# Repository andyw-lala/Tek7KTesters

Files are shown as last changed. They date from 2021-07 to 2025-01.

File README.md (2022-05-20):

# Tek7KTesters

Project to create modern test fixtures/plug-ins for the Tektronix 7000-series scope mainframes.
For more info on the 7000 series, see the excellent [Tekwiki](https://w140.com/tekwiki/wiki/Introduction_to_the_7000-Series).

7000-series calibration plug-ins are a rare beast, and usually expensive when they can be found.

This project hopes to create some new calibration & test solutions, with circuit ideas and software that can be reused, mixed-and-matched, extended, and improved. Where appropriate, modern chip-level solutions are encouraged to be used, examples include: differential drivers (both analog and LVDS), and microcontrollers.

Some of this work may be applicable or portable to other Tek plug-in based scopes, such as the 5000 series, but I don't own any of those (yet.)

## Contents:

### [Tek 7K Breakout Board](/Breakout)
This is a simple breakout board to facilitate experimentation and development using the Tek 7000 backplane connections.

### [Pattern Generator](/Pattern)
Circuit to generate test patterns, consisting of vertical lines, horizontal lines, vertical and horizontal lines, and dots.
Based on the Infineon (nee Cypress) PSOC5LP, plus required external circuitry.

### [Readout Interface](/Readout)
Circuit to interface the mainframe's readout subsystem to the PSoC, to permit displaying of arbitrary information, and/or testing of the mainframe readout system.

## Licence
All work here is covered by the MIT Licence, which is simple and permissive.

## Background
There is information to be found in many places, but a great starting point is [Tektronix 7000-Series Plug-in to Mainframe Interface Manual](https://w140.com/tekwiki/images/7/7c/Tek_7000-series_plug-in_mainframe_interface_manual_ocr.pdf). Originally a Tek-internal engineering document, now freely available.

Manuals for original calibration/test fixtures:
* [067-0587-01](http://w140.com/tek_067_0587_01.pdf)
* [067-0587-02](http://w140.com/tek-067-0587-02.pdf)
* [067-0587-10](http://w140.com/tek_067-0587-10_service.pdf)
* [067-0711-99](https://w140.com/tekwiki/images/8/87/Tek_067-0711-99.pdf)
* [7M13](https://w140.com/tekwiki/images/3/33/070-1577-00.pdf)

The [TekScopes mailing list](https://groups.io/g/TekScopes) is an invaluable source of knowledge, experience, and expertize on all Tek oscilliscopes, not just the 7000-series.

## TODO
* Fast edge driver, ideas include LVDS drivers, or MAX3949 (like the Leo Bodnar pulser I have that happily does <40pS edges, I like this because it is configurable to some extent)
* Levelling amp, will likely think about this last, as I believe it will be the most difficult subsystem to get right, and make repeatable, especially up to 7104 bandwidths..

## Disclaimer
This project is presented as-is, all work and consequences are your sole responsibility. Do not work on Tek 7000 scopes unless you have the skills and knowledge to work safely, they contain **lethal** voltages. You perform all work at your own risk, and I have no responsibility for any damage or injury whatsoever.

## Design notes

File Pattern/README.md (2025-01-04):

# Pattern Generator
Generate various test patterns, including:
* Horizontal lines
* Vertical lines
* Cross-hatch (combination of horizontal and vertical lines)
* Field of dots

The lines can either be coarse and match only the major graticule markings (11 horizontal, 9 vertical), or fine and align with both major and minor graticule markings (51 total horizontal, 41 total vertical.)

The field of dots is designed to produce a dot at every intersection of the major graticule markings only.
Optionally produce Z axis signal(s) to highlight the central graticule lines (and also all major graticule markings when producing the fine liones or crosshatch.

All signals are brought out to front panel connectors (100mV per division, single-ended), and driven to the approriate backplane connections (50mV per division differential.)

## Overview
There are 4 signal sources used in various combinations to support each mode:
1. Ramp Generator

   This uses a current DAC in the PSoC to charge a capacitor, generating a linear ramp. This signal is then conditioned to be symmetrical around ground, and have the approriate amplitude.
2. X & Y Step Generators

   These are identical, and each also use a current DAC in the PSoC to develop a voltage across a precision resistor. These signals are then conditioned in a similar manner to the ramp signal.
3. Z Axis driver

   This uses a voltage DAC in the PSoC, to provide a voltage that is converted into a control current in the range -4 to +4 mA which can modulate the trace intensity (max intensity to full blanking, respectively.)

The ramp and step signals are highly configurable, and also switched/routed according to the desired pattern and the location of the test plug-in in the mainframe (more on this later.)
In addition to directly driving the approriate backplane signals, these are also brought out to front panel BNC connectors. Usually one of these is used to connect to a suitable plug-in to provide the "other" signal (e.g., in a vertical slot, if the tester is using a horizontal slot.)

The Tek 067-0587-* fixtures could generate either 11 or 110 lines, with sweeps from 10Hz to 1MHz.
The new fixture can generate 11 or 51 vertical lines, and 9 or 41 horizontal lines, with sweeps from approximately 50Hz to 450KHz, and independently control the ramp repetition frequency in 500nS steps. At very slow speeds, the signals are so sparse that it can be difficult to visually align with the graticule markings; at the very fastest speeds, the software can begin to have trouble setting up additional signals such as the Z Axis output, resulting in inconsistent trace intensity.
The independent and highly configurable ramp time and ramp repetition frequency , combined with flexible signal routing allows for a great range of possible test patterns and speeds.

# Additional Signals
In addition to the differential signals and Aux Z axis outputs provided to the backplane, and the vertical and horizontal front panel outputs, several additional signals are implemented.
## Outputs
The following signals are provided:
* Sweep Trigger Output (front panel BNC) 
* \+ Trigger Out (backplane A13)
* Sweep Gate (backplane A1)
* Hold Off (backplane B4)
* Aux Y (backplane B16)
## Inputs
The following inputs are used:
* Chop Drive (backplane A5)

The following inputs are terminated in 50Ohm, but not used:
* +/- Trigger In (backplane A20/B20)

[CY8CKIT-059](https://www.mouser.com/ProductDetail/Cypress-Semiconductor/CY8CKIT-059)

[PSoC Creator IDE](https://www.cypress.com/products/psoc-creator-integrated-design-environment-ide)

TODO:
* block diagram
* PSoC Creator files

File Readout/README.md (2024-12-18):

# Readout-related circuits
The 7000-series readout circuitry is a clever, subtle, and novel solution, as you would expect once you learn that the designer was [Barrie Gilbert](https://w140.com/tekwiki/wiki/Barrie_Gilbert).
It is based on circuitry in the mainframe scanning the modules for characters to display in specific timeslots.
There are 10 possible timeslots (character positions) per screen location, and 2 screen locations per plug-in bay (e.g., 8 total screen locations in a 7904A, for a maximum total of 80 characters, though far fewer are displayed in normal operation.)
Display characters, or other metadata, are encoded in each timeslot by two currents (row and column) per location.
Currents are encoded in 100uA steps.
Modules need to always be prepared to sink either two or four currents to drive the display, but while the timeslot signals are simply bussed across all plug-in bays, the mainframe is paying attention to only one plug-in at a time (there is no indication to a plug-in that it is the active one.)
The system can be fully implemented by passive components and wiring and/or switches, including modifying scales/prefixes. Changes can be accomplished simply by summing currents, and common scope operations (e.g., input sensitivity modification by x10, x100, x1000 probes) are easily implemented by plug-ins using simple, but sometimes subtle, solutions.

## Interfaces
There are two interfaces needed to interact with the 7000-series readout system - one from the mainframe to the plug-ins and one from the plug-ins to the mainframe:

### Timeslot Signals

There are ten timeslot scanning signals from the mainframe to the plug-in.
Each individual timeslot signal is activated in a repeating sequence.
Each pulse is ~130-250uS wide and drives from ground to -15V, but is carefully slew-rate controlled, in order to avoid generating noise in sensitive plug-ins.
The timing is not explicitly specified in the documentation (that I can find), specifically when the current sinks are sampled, or setup/hold times.

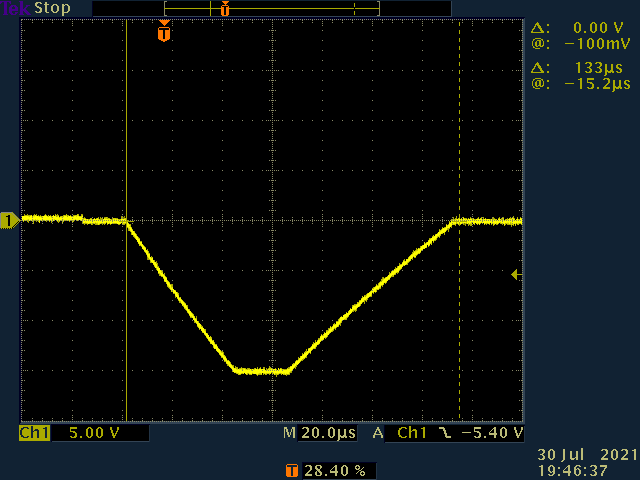
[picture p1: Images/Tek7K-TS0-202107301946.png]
TS0 Pulse


The above image clearly shows a timeslot pulse that is around 130us wide, with a plateau at -15V between approximately 45us and 65us, which is where the sampling must occur for the specified resistor values to generate the appropriate currents.

More details can be found on [TekWiki](https://w140.com/tekwiki/wiki/7000_series_readout_system).

# Interfacing to PSoC

Adapting the timeslot input circuitry used on the 7D11, the timeslot pulses from the mainframe are fed to a JFET, which is normally conducting, with its drain at 0V. When the TS pulse starts to go negative, the JFET will turn off, allowing the voltage at the drain to rise. Since the PSoC lacks schmitt trigger inputs, we use on-chip comparators with hysterisis enabled to condition the input signal. This circuit is implemented twice, once for TS1 and once for all the other TS signals, diode or-ed together. A 100K pull-down resistor on the JFET gate ensures a timely turn on of the fet as the diodes would otherwise isolate the gate. Although the TS1 signal strictly speaking does not require the diode, it is implemented so that the circuitry and timing seen by each timeslot is identical.

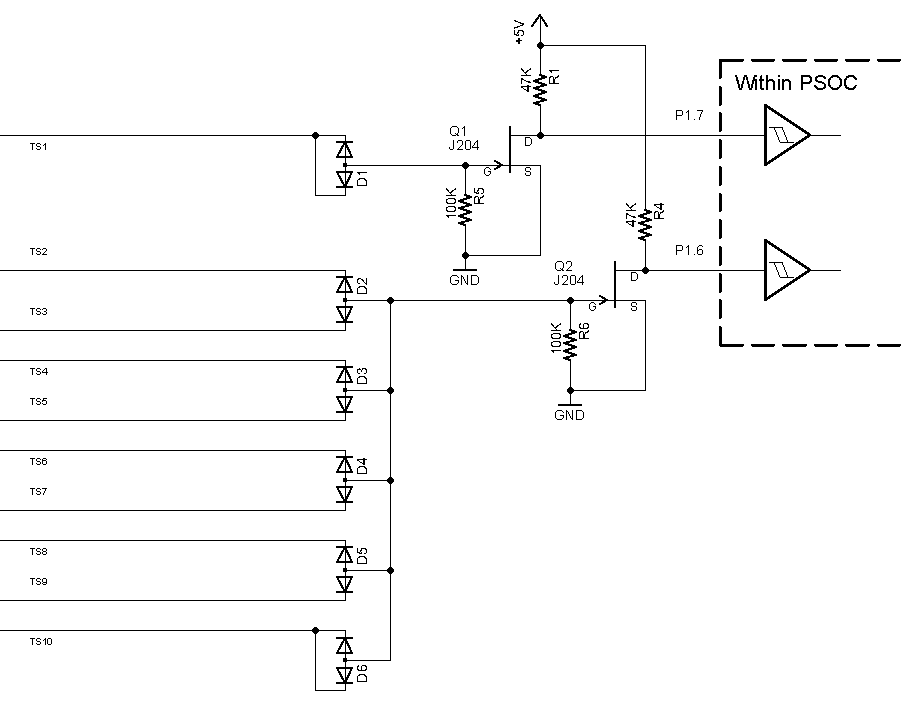
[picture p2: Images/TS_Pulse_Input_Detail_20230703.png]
Input Conditioning


This circuit offers approximately 57 uS lead-time from the input signal crossing the 1.024 V threshold to the bottom of the input pulse when the current sinks need to be set-up.

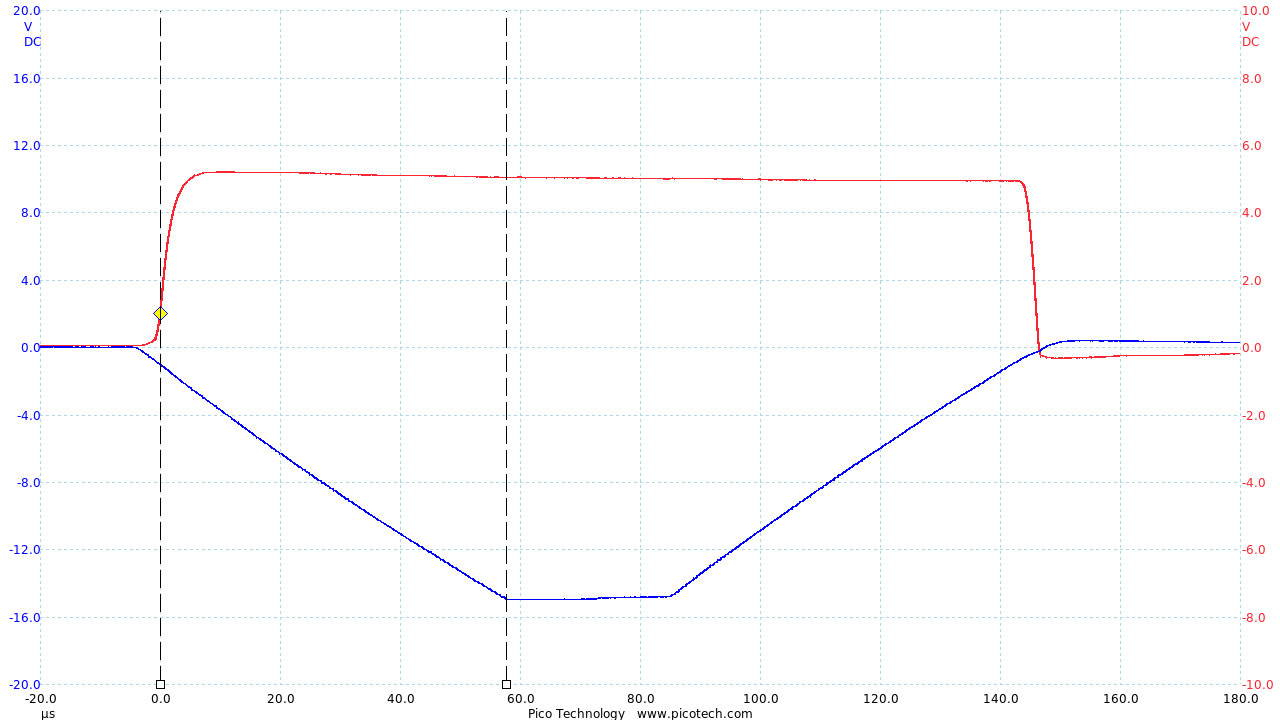
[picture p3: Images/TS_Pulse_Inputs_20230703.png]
Input Timing


The blue trace (LH axis) is the input pulse from the mainframe, red trace (RH axis) is the signal as seen by the PSoC.

The following image shows the same input pulse in blue, but the red trace reflects the time spent in the interrupt handler on the ARM CPU in the PSoC (note the timebase change from 20us to 10us per division.) The ISR is reading the timeslot value from the counter and then writing new values to the readout current circuitry via the shift registers described below. In practice, additional lookups will be involved, but that will hardly impact the duration of the ISR.

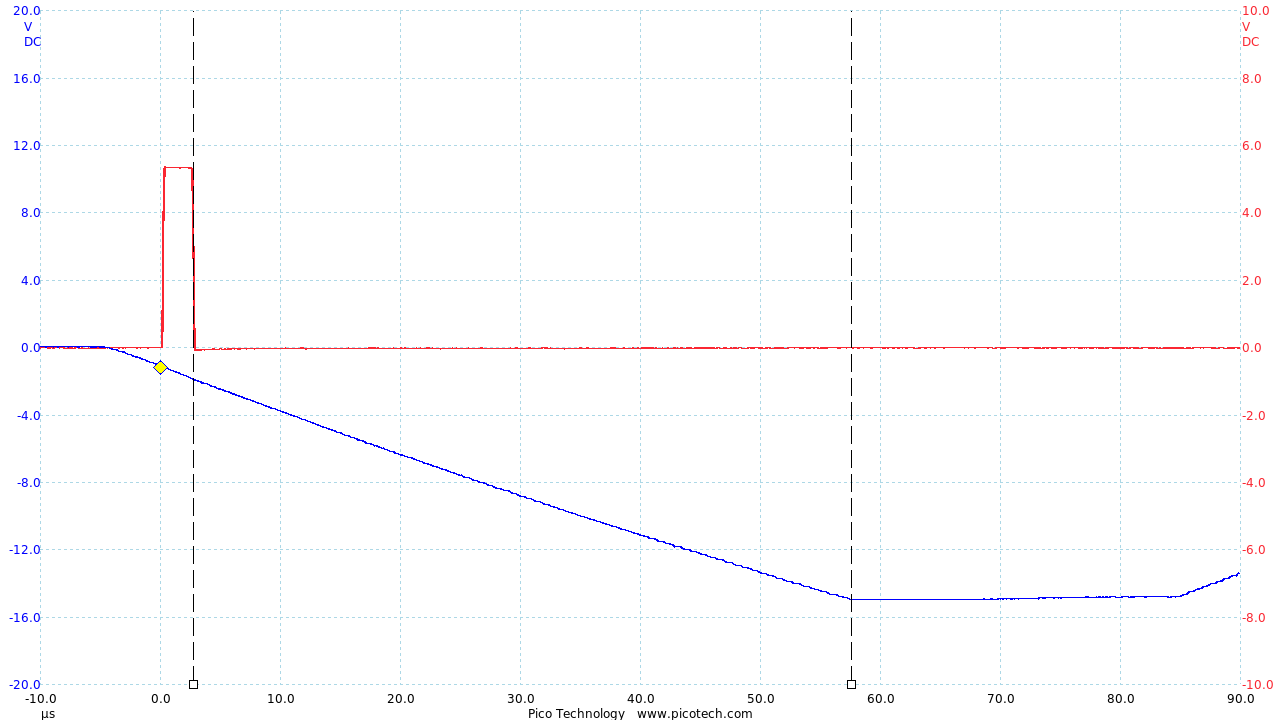
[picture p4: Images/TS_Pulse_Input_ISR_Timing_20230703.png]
Input ISR Timing


This demonstrates that the solution will work, and as long as we do not mask interrupts for extended periods we can use software to service the readout circuitry.

Note that should the PSoC become unable to service interrupts (due to firmware crash, reset, flashing, or debugger activity) the readout will not longer be updated for each timeslot, resulting in each display field filling with the same character (usually the last one written just before interrupts were no longer serviced.) Each display field can show different characters.

## PSoC Connectivity

### Inputs

The timeslot input circuitry uses two pins of analog I/O into the PSoC.
Internally these are conditioned via comparators (as described above) and used to maintain a counter of the most recent timeslot requested, and generate interrupts so that the firmware can determine the approriate row/column currents for each channel.

Combining the nine timeslot signals as shown reduces the number of input pins required, at the cost of obscuring specific timeslot outputs from the mainframe that may be malfunctioning.

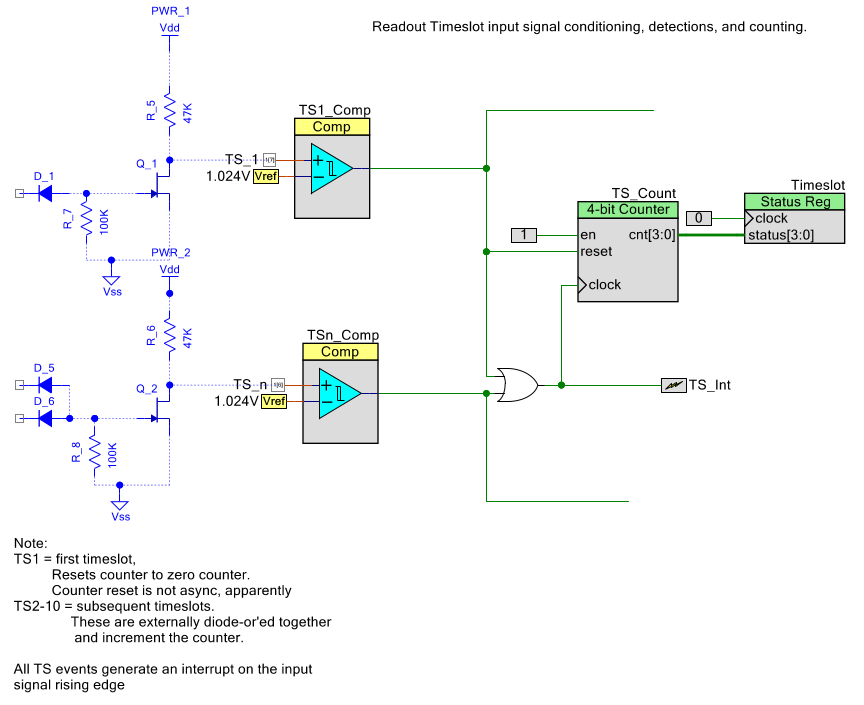
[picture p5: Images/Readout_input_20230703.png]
TS Input


### Outputs

Output requires 16 bits of digital GPIO for the maximum of four current sinks, while this may be possible directly with specific members of the PSoC device family, it was highly desirable to be able to use the CY8CKIT-059, meaning that the available GPIO pin count was constrained. Initially a Microchip MCP23S17 I/O expander using SPI was prototyped, but the final design uses two 74HC595 shift registers coupled with a simple driver circuit implemented in the PSoC as a write-only 16-bit port expander. Each 595 shift register implemets 8 bits (4 row + 4 column) required for one channel. These are daisy-chained, so that the PSoC clocks 16 bits out in one operation and then strobes the register clock line to simultaneously present all 16 bits to the current generation circuits.

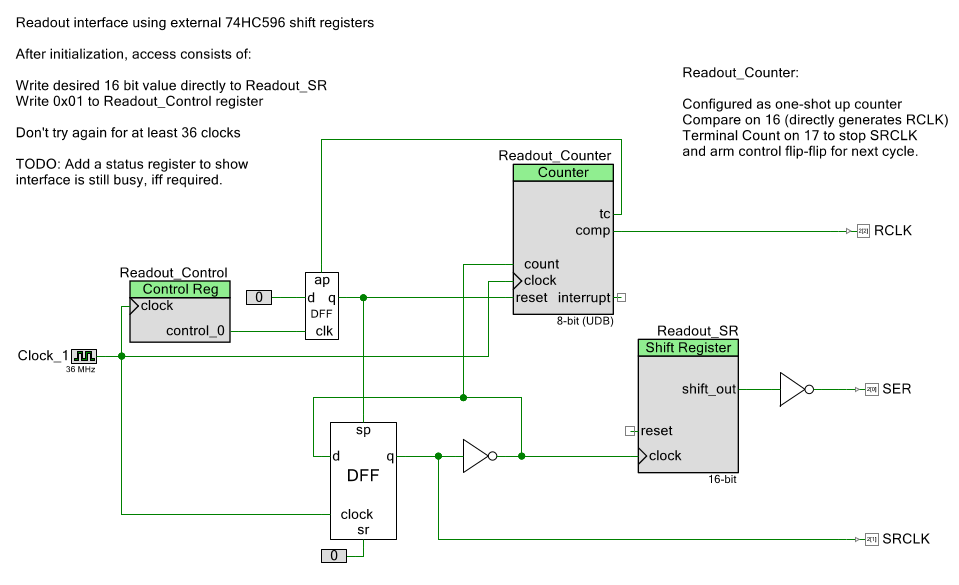
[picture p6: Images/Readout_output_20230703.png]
TS Output Logic


### Readout Row and Column Currents
Four identical current sinks (two channels, each with independent row & column currents) encode the data for the currently indicated timeslot.  
Channel 1 data will appear at the top of the screen, Channel 2 data will appear at the bottom of the screen.

The circuit used is shown below:

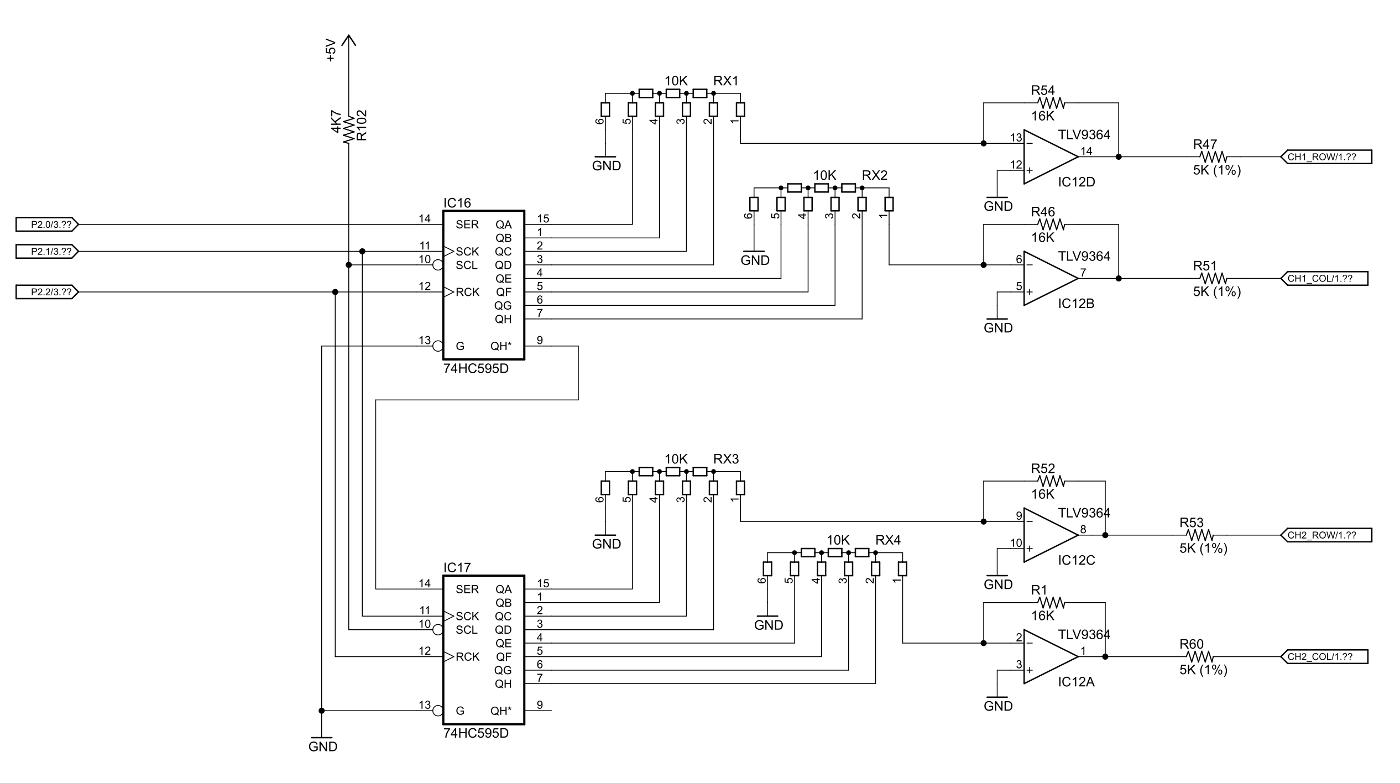
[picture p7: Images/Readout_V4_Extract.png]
Readout Current Sink


The parallel outputs of the shift registers drive four independent 4-bit [R-2R voltage DACs](https://en.wikipedia.org/wiki/Resistor_ladder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). These output 0 - 4.6875V, in 312.5mV steps, for values between 0 and 15 respectively. Note that R-2R ladders maintain a fixed impedance, equal to R regardless of input value.

As described above, the mainframe samples the current flowing out of the mainframe row and current sense pins on the backplane in 100uA steps when the timeslot signals are stable at -15V (the middle of the pulse.)
These mainframe row and current sense pins are nominally at ground.
The current is developed by applying negative voltages across fixed resistors connected to the mainframe row and column pins. Since 5K precision (1%) resistors are aleady used elsewhere in the design, this value was selected.
100uA corresponds to 500mV across a 5K resistor, therefore a simple inverting amplifier with a gain of -1.6 (recall that the impedance seen looking into the R-2R ladder will always be 10K, hence the feedback resistor of 16K) is used to convert the positive-going DAC output voltage into a suitable negative voltage. Converting each 312.5mV step from the DAC into -500mV at the output of the opamp, resulting in 100uA current per-step flowing out of the mainframe sense pins. The maximum negative voltage generated for a code of 15 is -7.5V.

Thus we can generate four independent 0 - 1500uA current sinks at 100uA resolution, using only 3 digital pins on the PSoC, and three low-cost ICs. The total PSoC pin count used for the readout interface is five: 2 analog inputs and three digital outputs.

## Demonstration of circuit in action
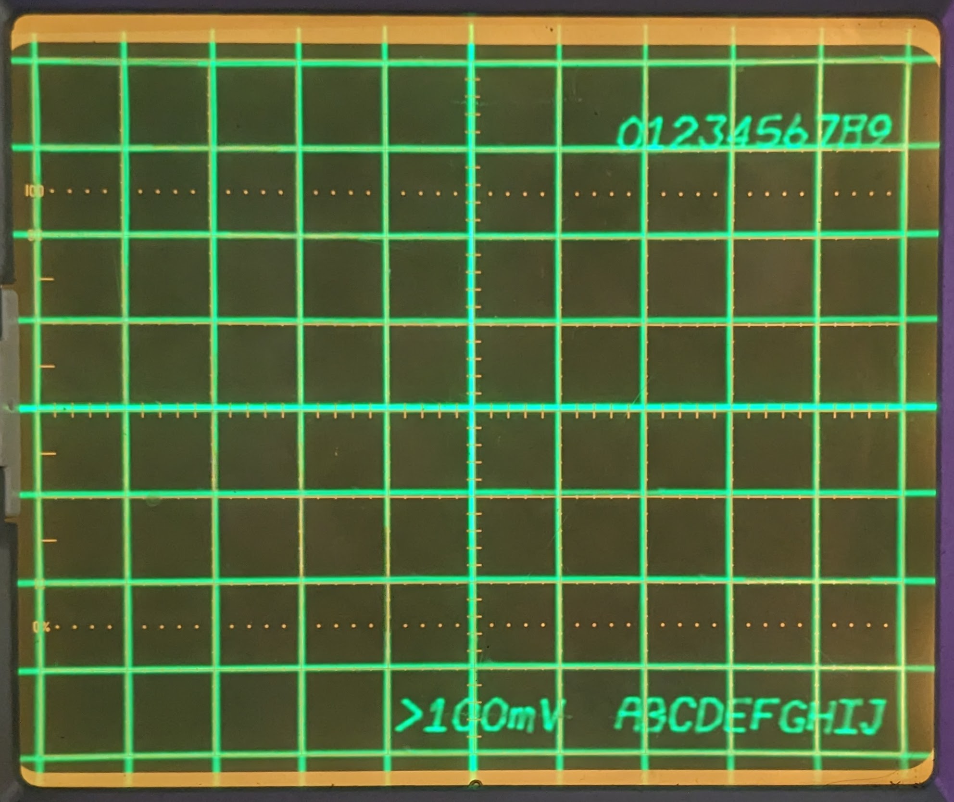
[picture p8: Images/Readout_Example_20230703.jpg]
Image of readout display


This is generated by the following crude code with magic numbers:

```
void
Readout_Write(uint8 ch1, uint8 ch2)
{
    uint16 readout = ch1 | (ch2 << 8);
    /*
     * Row is lower nibble of each byte, column is the upper nibble.
     */
    Readout_SR_WriteRegValue(readout);
    Readout_Control_Write(0x01);
}
static char top[10] = {0x10, 0x20, 0x30, 0x40, 0x50, 0x60, 0x70, 0x80, 0x90, 0xa0};
static char bottom[10] = {0x34, 0x74, 0x81, 0xa5, 0xa4, 0x75, 0x83, 0x54, 0x31, 0x85};

CY_ISR (TS_ISR)
{
    uint8 ts;
    
    ts = Timeslot_Read();
    
    if (ts >= 10) {
        Readout_Write(0x53, 0x53);
    } else {
        Readout_Write(top[ts], bottom[ts]);
    }
}
```

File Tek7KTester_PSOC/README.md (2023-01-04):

# Tek7KTesters_PSOC

This subdirectory contains the PSoC creator files to instantiate the PSOC solution that drives the tester.

TODO:
* Figure out how to specify relative files, the paths in many of the PSoC Creator files are currently absolute, making this git repo something wildly less than portable. Currently this subdirectory needs to be spoon-fed to PSoC Creator.
* Trim the content held in git as much as possible, forcing PCoC Creator to regenerate files it can as needed.
* Tune the .gitignore file to ensure we don't pick up cruft.
* Correctly set up Debug/Release builds.
* Verified to work with PSoC Creator 4.4

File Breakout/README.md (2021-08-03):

# 7000-series Backplane Breakout Board
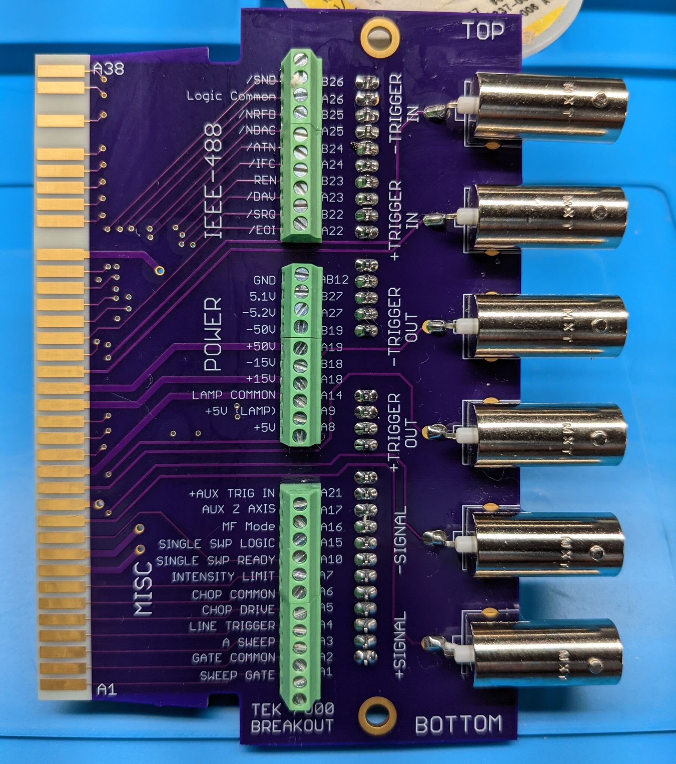
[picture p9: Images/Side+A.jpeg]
Side A

## Version 1
This board brings out the most commonly used high speed signals out to BNC connectors, and low-speed or power signals to screw connectors.  
The design intent is to allow cables to be routed via the front or sides of the scope for connection to external circuits or test equipment.

### [Board Outline](/Breakout/Tek7000_Breakout_v1_Outline.pdf)
A crude dimensioned drawing of the basic board outline for the V1 breakout board.  
I make no apologies for the mixed units - the edge connector width is tied directly to the 38-way 0.1" edge connector, and the board width was clearly intended to be 4.5".
All other dimensions were directly measured with a caliper from multiple 7000 plug-in modules.  
Form, fit, and function have been validated with plug-in frames, including the rear plastic housing (e.g., Tek part number 386-1402-00.)

### Eagle Files
[Schematic](/Breakout/V1.sch) and [board](/Breakout/V1.brd) files for a 4-layer implementation.  
High speed signals are designed to be *approximately* 50Ohm traces, but no attention has been paid to matching the signal path length for the differential signal pairs.  
Note also that the board file does not include any indication for hard gold plating on the edge connector, or chamfering of the board edge.

### BOM
The V1 board is designed for the following connectors:
* BNC (Qty 6)  
  Molex part number: 73171-3150  
  Mouser part number: 538-73171-3150
* Low Speed/Power  
  Pheonix Combicon MPT 0.1" pitch side entry screw connectors  
  Terminal count as required, TODO: list here

It is also possible to omit any or all of the connectors altogether and solder wires directly to the board, if desired.

### OSHpark Project
The V1 board is available as a shared project from [OSHpark](https://oshpark.com/shared_projects/c7Hx5qZ4).  
**Note:** These boards only have ENIG finish on the edge connector fingers, as mentioned above; and do not have chamfered edges (see below.)

### Important Note
It is recommended by several members of the TekScopes mailing list to manually chamfer the edge connector with a file and clean to remove dust before inserting into a scope mainframe, in order to avoid possible damage to the backplane connectors. As mentioned above, the eagle files to not include this and OSHpark does not offer chamfering, so you need to do this manually for OSHpark boards.

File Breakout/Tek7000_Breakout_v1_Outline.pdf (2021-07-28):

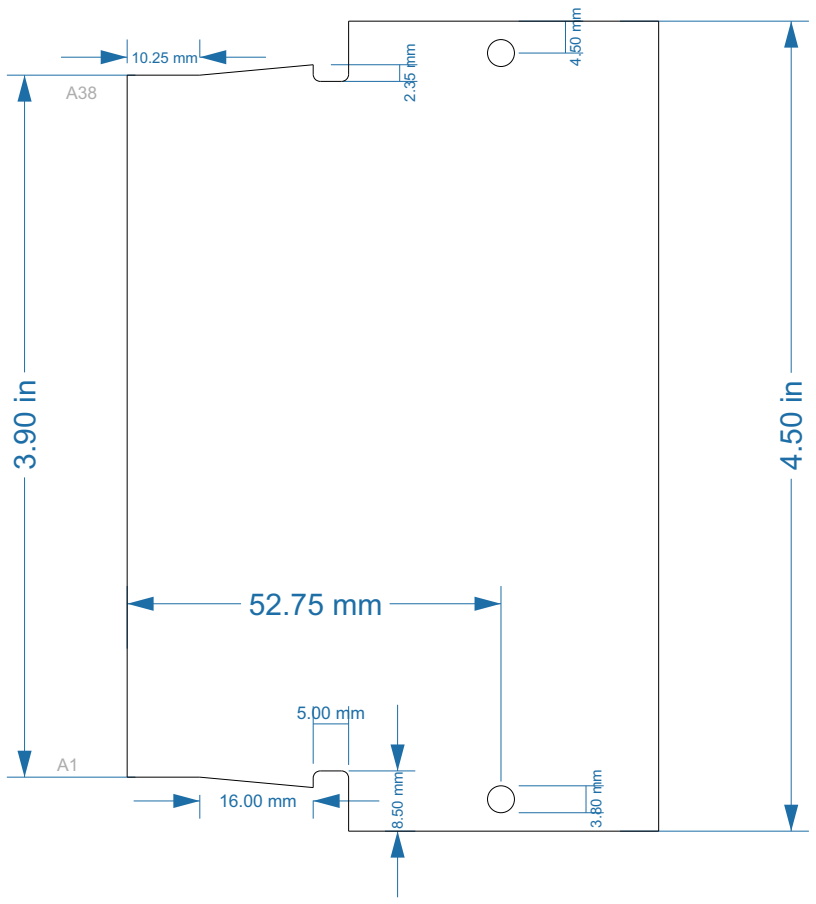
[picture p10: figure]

Tek 7000 Breakout Board v1 Outline

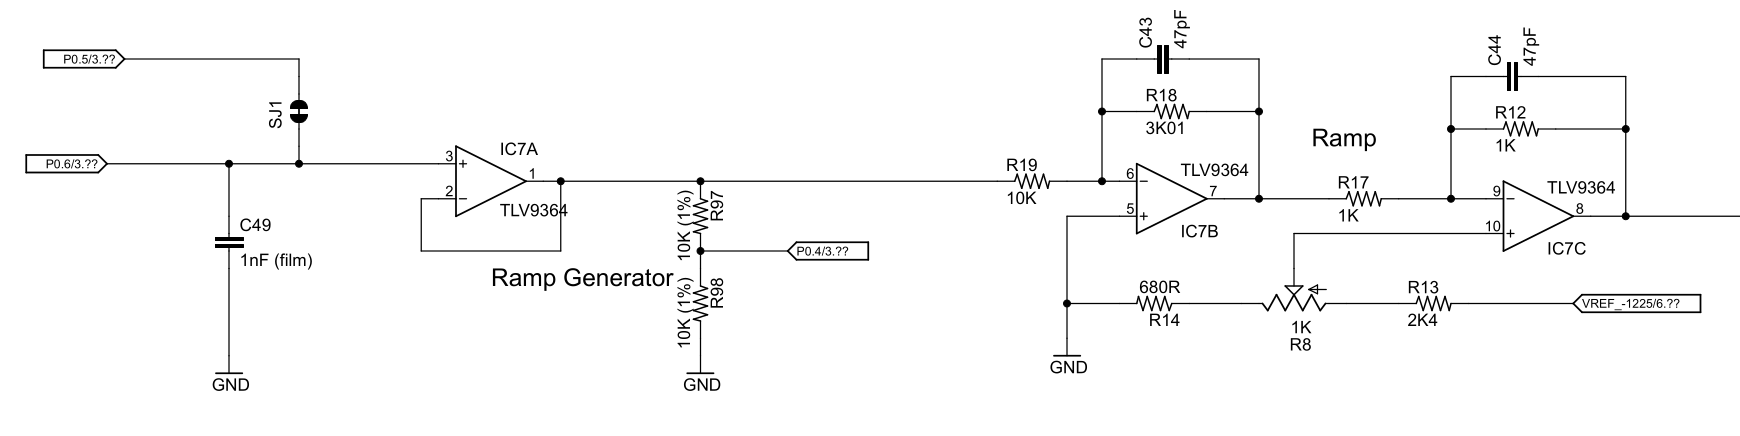
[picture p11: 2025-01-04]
Images/Ramp.png

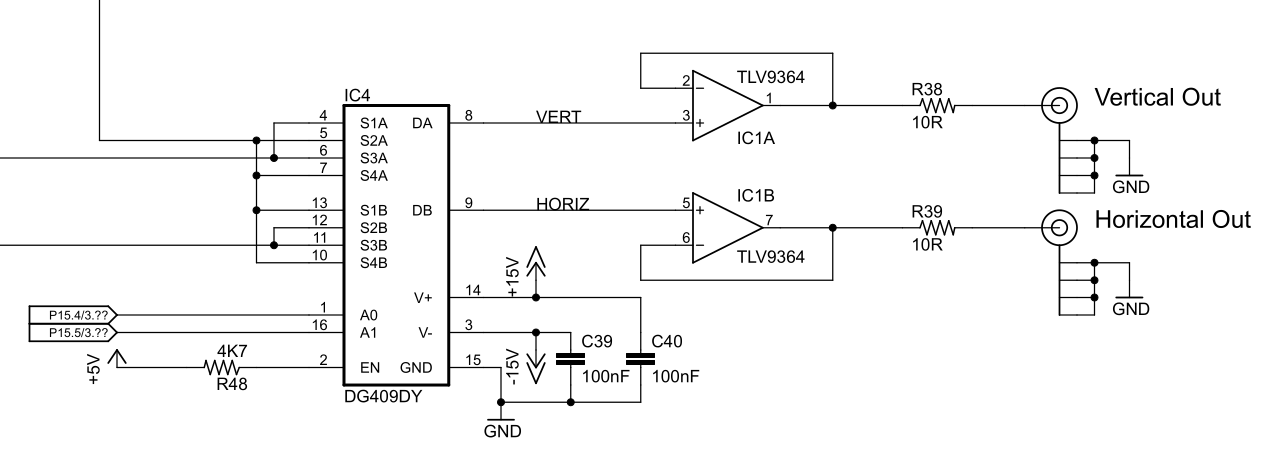
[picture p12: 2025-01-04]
Images/Routing.png

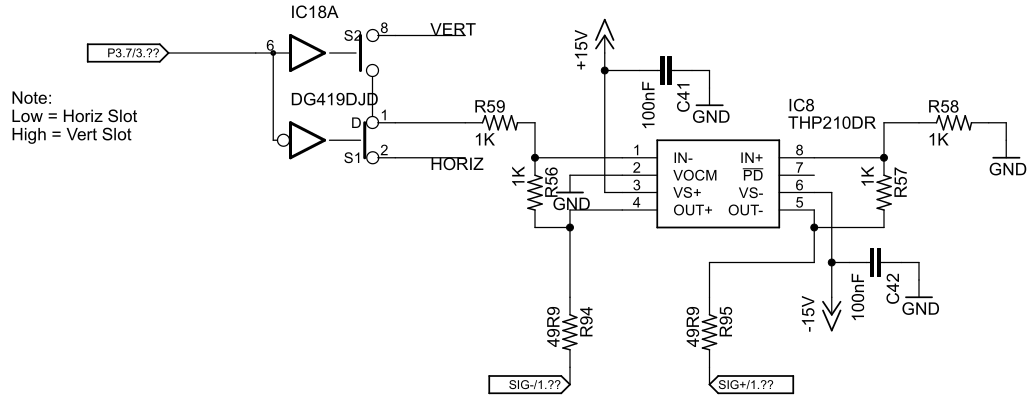
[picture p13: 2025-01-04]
Images/Backplane.png

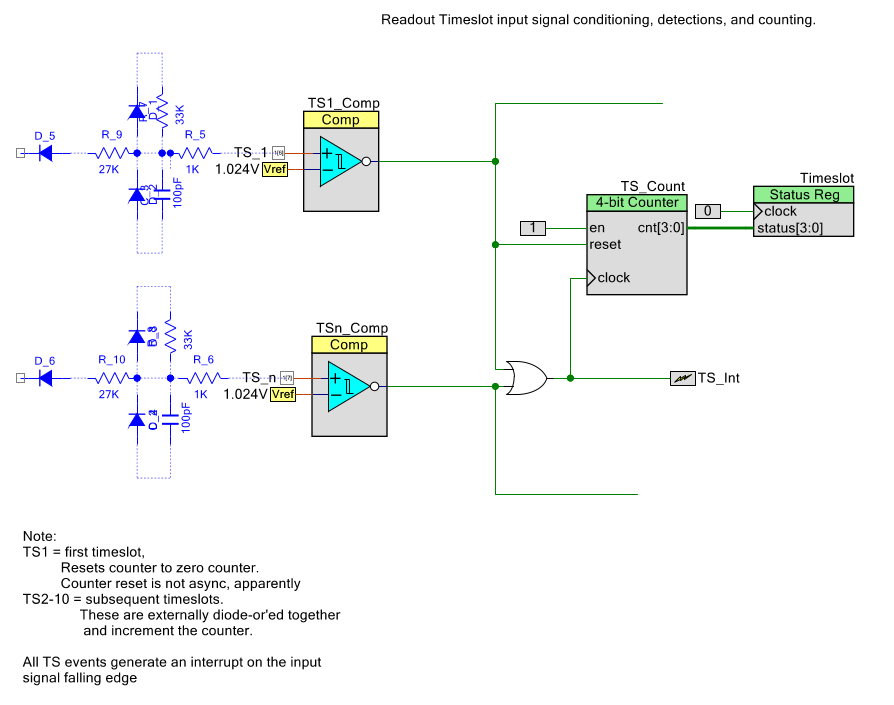
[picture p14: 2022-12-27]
Images/TS_Input.png

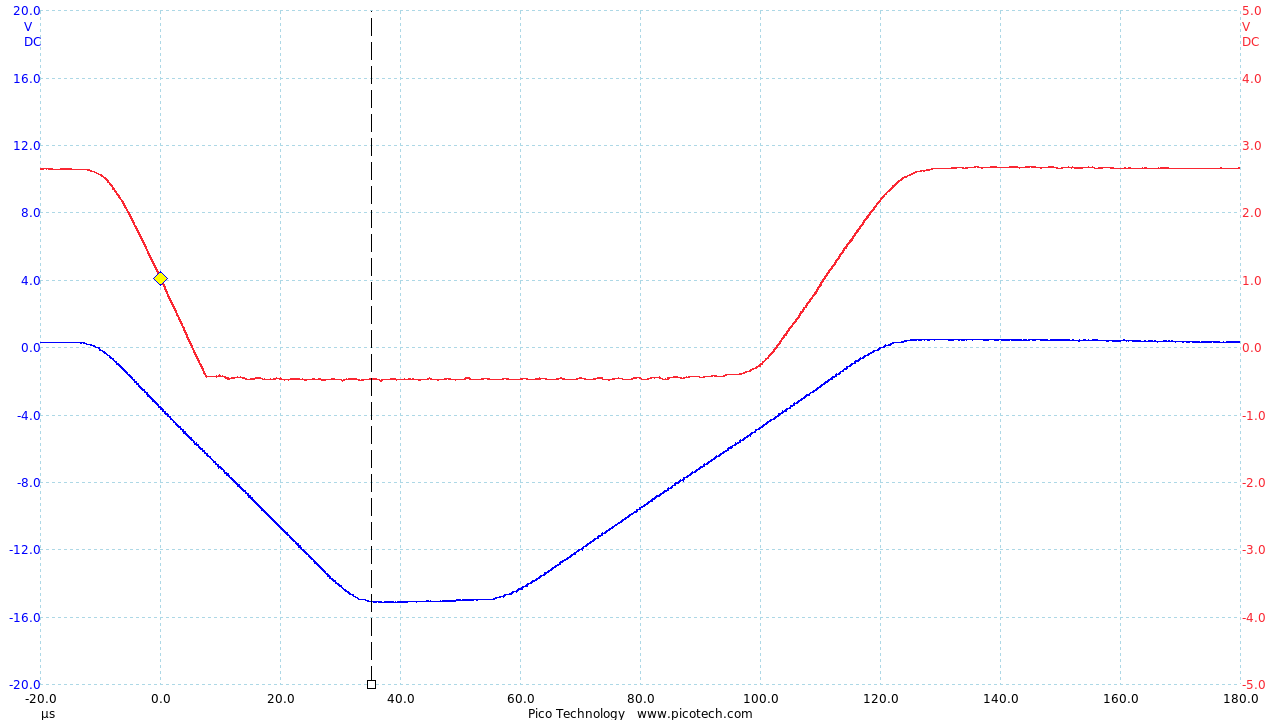
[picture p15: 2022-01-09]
Images/TS_Pulse_Input_Timing.png

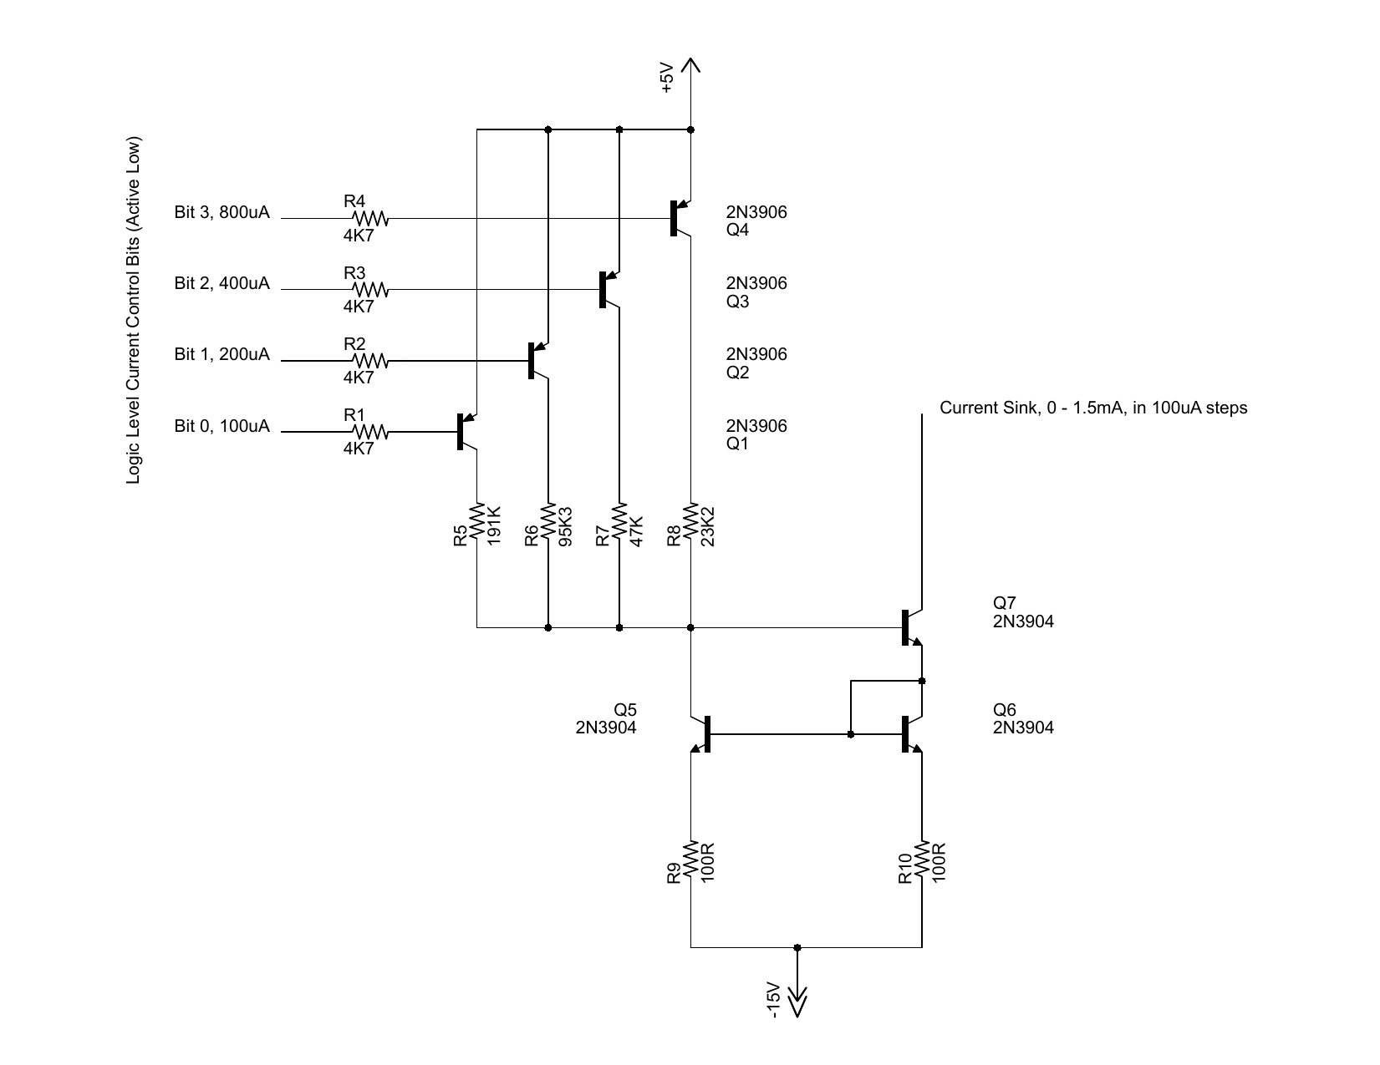
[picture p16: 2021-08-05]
Images/readout_current_sink_v1.png

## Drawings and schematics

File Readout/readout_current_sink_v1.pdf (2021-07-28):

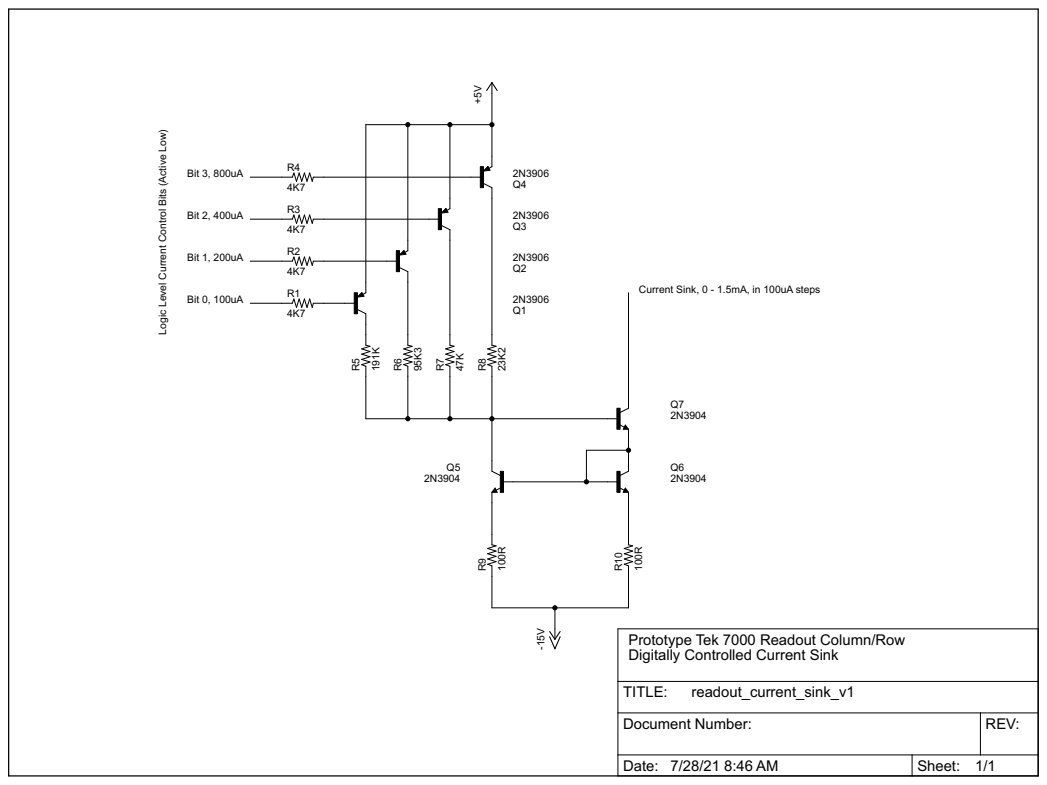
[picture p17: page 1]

Logic Level Current Control Bits (Active Low) Bit 0, 100uA

Current Sink, 0 - 1.5mA, in 100uA steps

Prototype Tek 7000 Readout Column/Row
Digitally Controlled Current Sink

Document Number: | REV:

Date: 7/28/21 8:46 AM | Sheet: 1/1

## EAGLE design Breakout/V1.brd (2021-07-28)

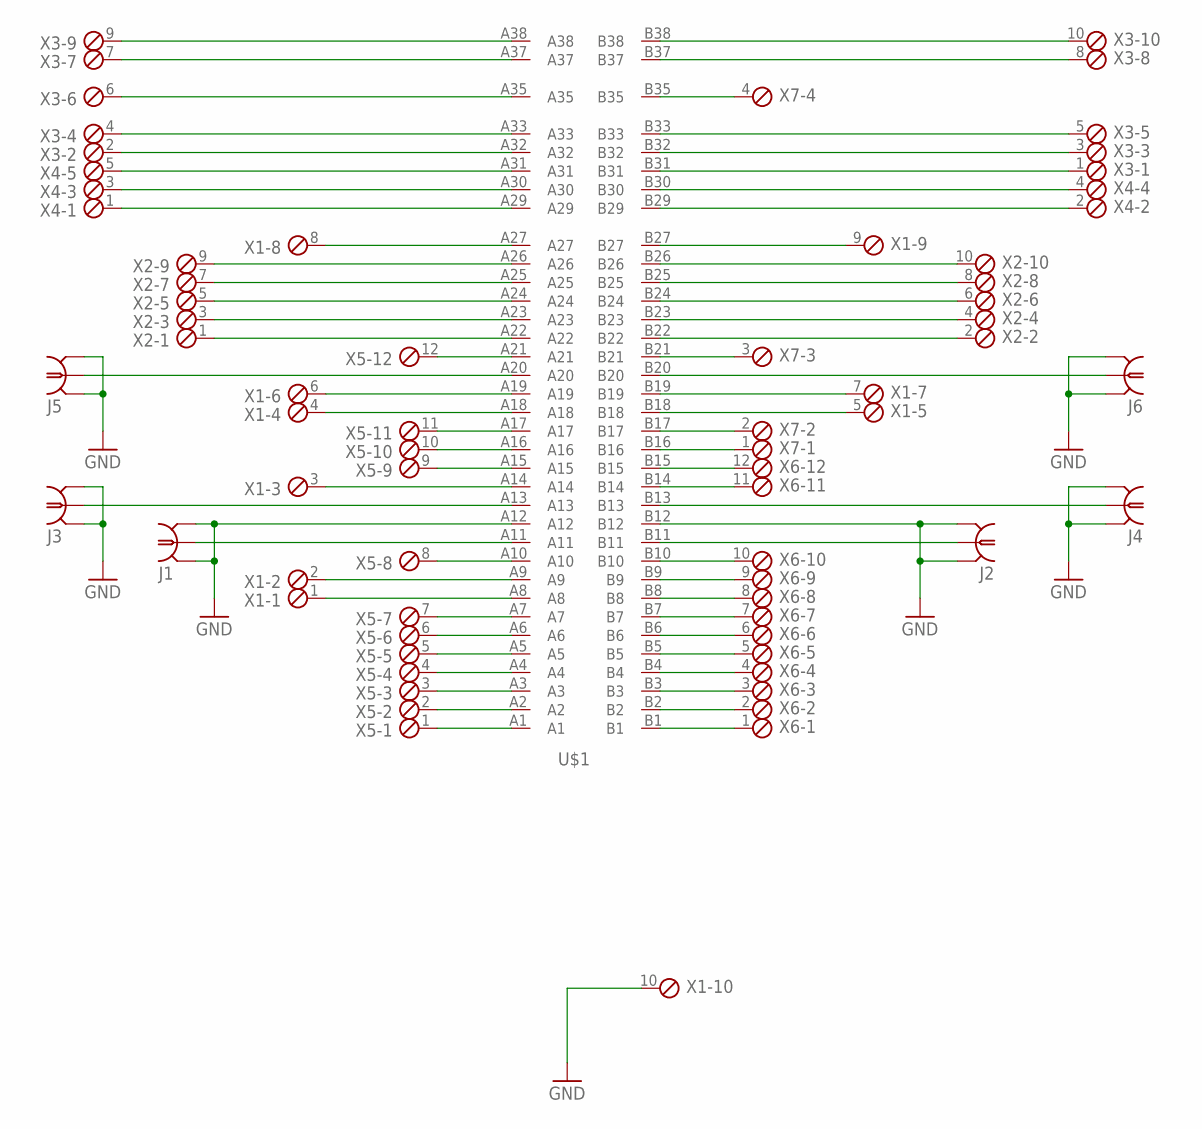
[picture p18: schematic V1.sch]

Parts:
J1, J2, J3, J4, J5, J6: BNC_MOLEX_73100; 73100
U$1: TEK_7000
X1, X2, X3: MPT10; 10POL254
X4: MPT5; 5POL254
X5, X6: MPT12; 12POL254
X7: MPT4; 4POL254

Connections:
GND: J1.GND, J1.GND@1 (GND), J2.GND, J2.GND@1 (GND), J3.GND, J3.GND@1 (GND), J4.GND, J4.GND@1 (GND), J5.GND, J5.GND@1 (GND), J6.GND, J6.GND@1 (GND), U$1.A12, U$1.B12, X1.10
unnamed: U$1.A1, X5.1
unnamed: U$1.A2, X5.2
unnamed: U$1.A3, X5.3
unnamed: U$1.A4, X5.4
unnamed: U$1.A5, X5.5
unnamed: U$1.A6, X5.6
unnamed: U$1.A7, X5.7
unnamed: U$1.A8, X1.1
unnamed: U$1.A9, X1.2
unnamed: U$1.A10, X5.8
unnamed: J1.SIG, U$1.A11
unnamed: J3.SIG, U$1.A13
unnamed: U$1.A14, X1.3
unnamed: U$1.A15, X5.9
unnamed: U$1.A16, X5.10
unnamed: U$1.A17, X5.11
unnamed: U$1.B1, X6.1
unnamed: U$1.B2, X6.2
unnamed: U$1.B3, X6.3
unnamed: U$1.B4, X6.4
unnamed: U$1.B5, X6.5
unnamed: U$1.B6, X6.6
unnamed: U$1.B7, X6.7
unnamed: U$1.B8, X6.8
unnamed: U$1.B9, X6.9
unnamed: U$1.B10, X6.10
unnamed: J2.SIG, U$1.B11
unnamed: J4.SIG, U$1.B13
unnamed: U$1.B14, X6.11
unnamed: U$1.B15, X6.12
unnamed: U$1.B16, X7.1
unnamed: U$1.B17, X7.2
unnamed: U$1.B18, X1.5
unnamed: U$1.B19, X1.7
unnamed: U$1.A18, X1.4
unnamed: U$1.A19, X1.6
unnamed: J6.SIG, U$1.B20
unnamed: J5.SIG, U$1.A20
unnamed: U$1.A21, X5.12
unnamed: U$1.B21, X7.3
unnamed: U$1.A27, X1.8
unnamed: U$1.B27, X1.9
unnamed: U$1.A26, X2.9
unnamed: U$1.A25, X2.7
unnamed: U$1.A24, X2.5
unnamed: U$1.A23, X2.3
unnamed: U$1.A22, X2.1
unnamed: U$1.B26, X2.10
unnamed: U$1.B25, X2.8
unnamed: U$1.B24, X2.6
unnamed: U$1.B23, X2.4
unnamed: U$1.B22, X2.2
unnamed: U$1.B35, X7.4
unnamed: U$1.A29, X4.1
unnamed: U$1.A30, X4.3
unnamed: U$1.A31, X4.5
unnamed: U$1.A32, X3.2
unnamed: U$1.A33, X3.4
unnamed: U$1.A35, X3.6
unnamed: U$1.A37, X3.7
unnamed: U$1.A38, X3.9
unnamed: U$1.B38, X3.10
unnamed: U$1.B37, X3.8
unnamed: U$1.B31, X3.1
unnamed: U$1.B32, X3.3
unnamed: U$1.B33, X3.5
unnamed: U$1.B30, X4.4
unnamed: U$1.B29, X4.2

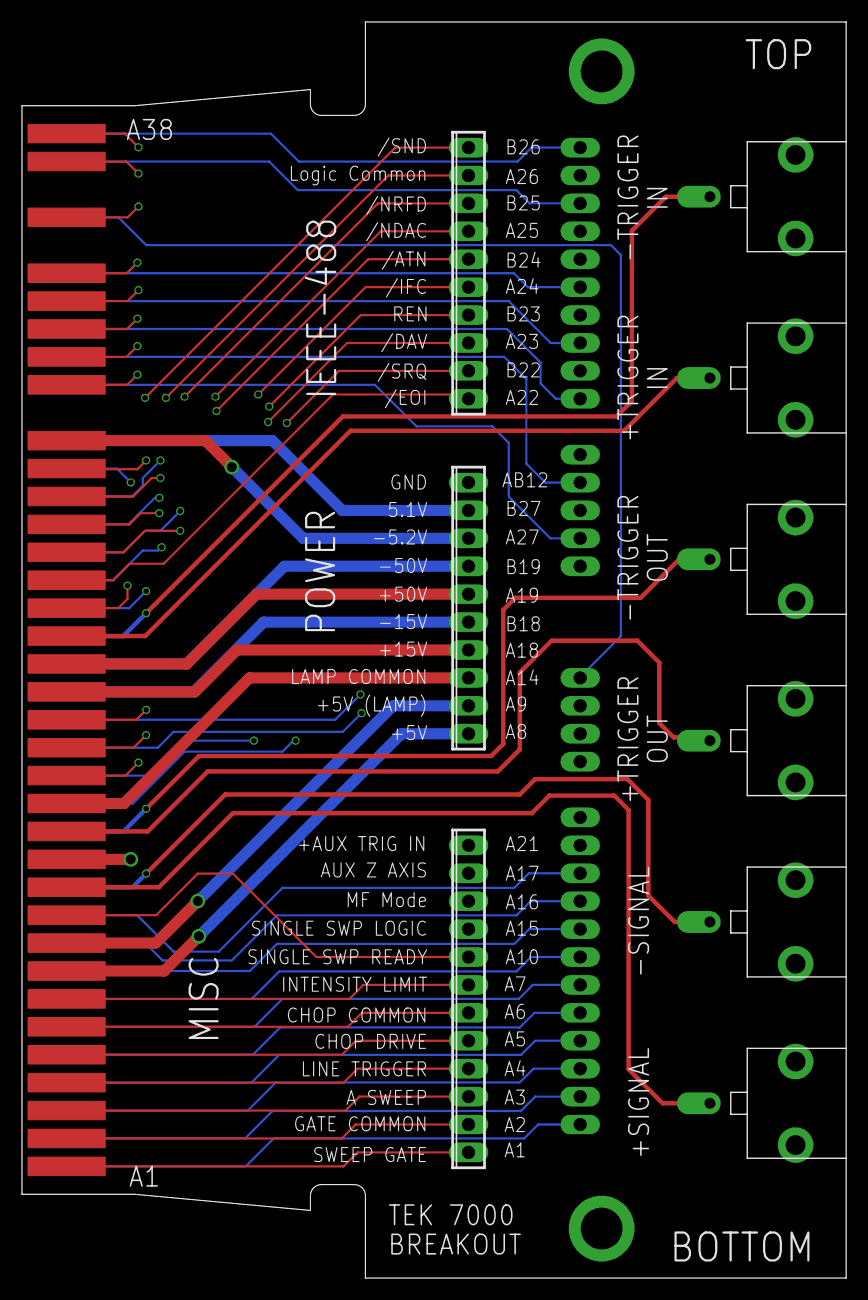
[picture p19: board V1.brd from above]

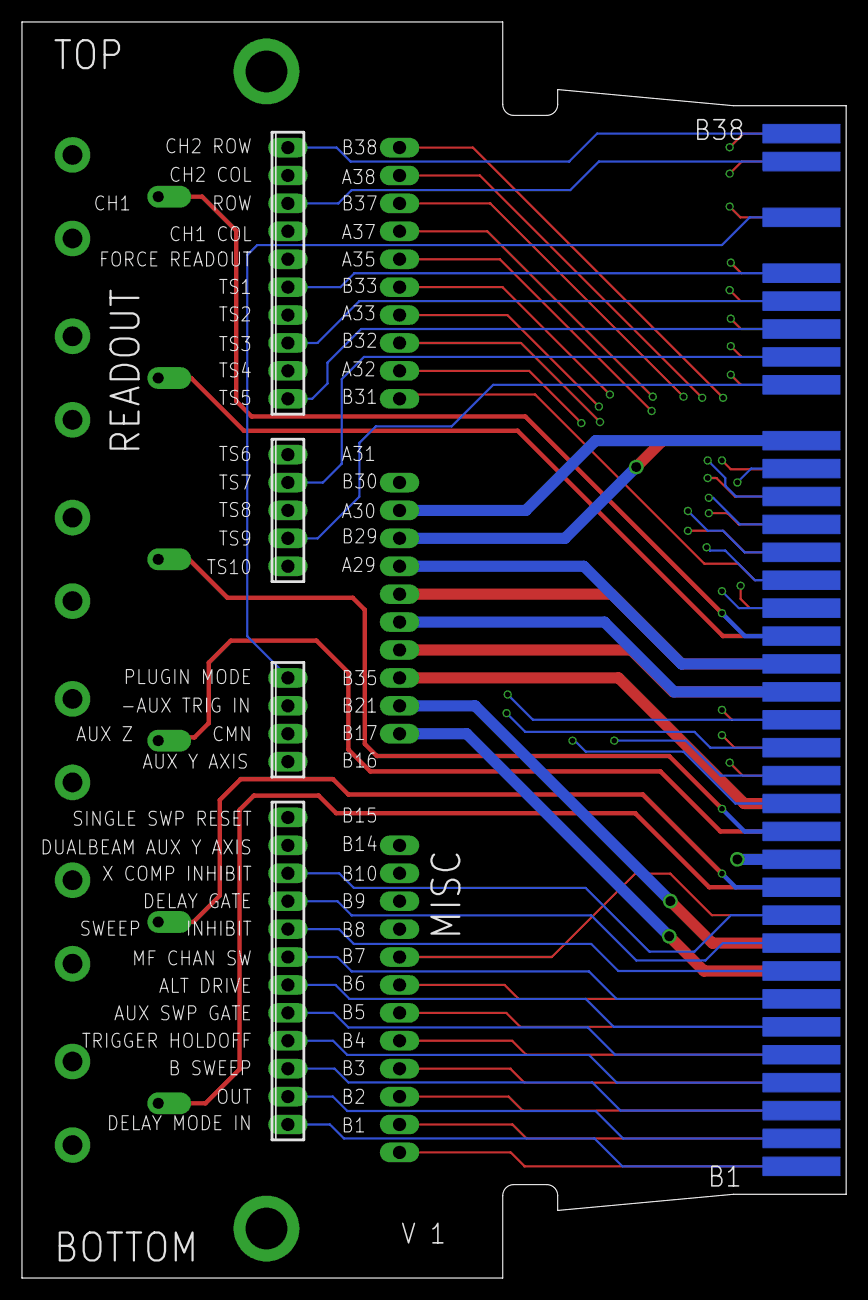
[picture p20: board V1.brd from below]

Board: 4 copper layers, 75.0 x 114.3 mm, 14 parts (4 on the bottom side), 69 nets.

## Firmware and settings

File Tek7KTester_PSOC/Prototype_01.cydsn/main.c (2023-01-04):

/*******************************************************************************
* File: main.c
*
* Version: 1.2
*
* Description: 
*   This is a source code for basic functionality of IDAC8.
*
********************************************************************************
* Copyright 2012, Cypress Semiconductor Corporation. All rights reserved.
* This software is owned by Cypress Semiconductor Corporation and is protected
* by and subject to worldwide patent and copyright laws and treaties.
* Therefore, you may use this software only as provided in the license agreement
* accompanying the software package from which you obtained this software.
* CYPRESS AND ITS SUPPLIERS MAKE NO WARRANTY OF ANY KIND, EXPRESS OR IMPLIED,
* WITH REGARD TO THIS SOFTWARE, INCLUDING, BUT NOT LIMITED TO, NONINFRINGEMENT,
* IMPLIED WARRANTIES OF MERCHANTABILITY AND FITNESS FOR A PARTICULAR PURPOSE.
*******************************************************************************/

#include <project.h>
#include "lcd.h"
#include "gui.h"
#include "test.h"   // DWD

enum    DisplayMode {OFF, HORIZ, VERT, XHATCH_HORIZ, XHATCH_VERT, DOTS, HORIZ_FINE, VERT_FINE, XHATCH_HORIZ_FINE, XHATCH_VERT_FINE};

enum DisplayMode display_mode = XHATCH_HORIZ_FINE;

uint8 lines_horiz[] = {68, 88, 108, 128, 148, 148, 148, 168, 188, 208, 228 } ;
uint8 lines_vert[] = {48, 68, 88, 108, 128, 148, 148, 148, 168, 188, 208, 228, 248 } ;
uint8 lines_horiz_fine[] = {68, 68, 72, 76, 80, 84, 88, 88, 92, 96, 100, 104, 108, 108,
                      112, 116, 120, 124, 128, 128, 132, 136, 140, 144, 148, 148, 148, 148,
                      152, 156, 160, 164, 168, 168, 172, 176, 180, 184, 188, 188,
                      192, 196, 200, 204, 208, 208, 212, 216, 220, 224, 228, 228};
uint8 lines_vert_fine[] = {48, 48, 52, 56, 60, 64, 68, 68, 72, 76, 80, 84, 88, 88, 92, 96, 100, 104, 108, 108,
                      112, 116, 120, 124, 128, 128, 132, 136, 140, 144, 148, 148, 148, 148,
                      152, 156, 160, 164, 168, 168, 172, 176, 180, 184, 188, 188,
                      192, 196, 200, 204, 208, 208, 212, 216, 220, 224, 228, 228, 232, 236, 240, 244, 248, 248};

CY_ISR (Sweep_End_ISR)
{
    static uint8 step = 0;
    // TODO: Bounds check step on mode change
    switch (display_mode) {
        case HORIZ:
        case XHATCH_HORIZ:
            StepY_IDAC_SetValue(lines_horiz[step]);
            if (++step >= (sizeof(lines_horiz)/sizeof(lines_horiz[0]))) {
                step = 0;
                if (display_mode == XHATCH_HORIZ) {
                    display_mode = XHATCH_VERT;
                    ModeReg_Write(1);
                }
            }
            break;
        
        case VERT:
        case XHATCH_VERT:
            StepX_IDAC_SetValue(lines_vert[step]);
            if (++step >= (sizeof(lines_vert)/sizeof(lines_vert[0]))) {
                step = 0;
                if (display_mode == XHATCH_VERT) {
                    display_mode = XHATCH_HORIZ;
                    ModeReg_Write(0);
                }
            }
            break;
            
        case HORIZ_FINE:
        case XHATCH_HORIZ_FINE:
            StepY_IDAC_SetValue(lines_horiz_fine[step]);
            if (++step >= (sizeof(lines_horiz_fine)/sizeof(lines_horiz_fine[0]))) {
                step = 0;
                if (display_mode == XHATCH_HORIZ_FINE) {
                    display_mode = XHATCH_VERT_FINE;
                    ModeReg_Write(1);
                }
            }
            break;
        
        case VERT_FINE:
        case XHATCH_VERT_FINE:
            StepX_IDAC_SetValue(lines_vert_fine[step]);
            if (++step >= (sizeof(lines_vert_fine)/sizeof(lines_vert_fine[0]))) {
                step = 0;
                if (display_mode == XHATCH_VERT_FINE) {
                    display_mode = XHATCH_HORIZ_FINE;
                    ModeReg_Write(0);
                }
            }
            break;
            
        case DOTS:
            StepY_IDAC_SetValue(lines_horiz[step % (sizeof(lines_horiz)/sizeof(lines_horiz[0]))]);
            StepX_IDAC_SetValue(lines_vert[step / (sizeof(lines_horiz)/sizeof(lines_horiz[0]))]);
            
            if (++step >= ((sizeof(lines_horiz)/sizeof(lines_horiz[0])) * (sizeof(lines_vert)/sizeof(lines_vert[0])))) {
                step = 0;
            }
            break;
    }
}

uint8 foo;

void
Readout_Init(void)
{
    Readout_Control_Write(0x01); 
    Readout_Counter_Start();
    Readout_SR_Start();
}

void
Readout_Write(uint8 ch1, uint8 ch2)
{
    uint16 readout = ch1 | (ch2 << 8);
    
    Readout_SR_WriteRegValue(~readout);
    Readout_Control_Write(0x01);
}

CY_ISR (TS_ISR)
{
    uint8 ts;
    
    lala_Write(0x01);
    
    ts = Timeslot_Read();

    Readout_Write((ts & 0x0f) | ((ts << 4) & 0xf0), (ts & 0x0f) | ((ts << 4) & 0xf0));
    
    
    lala_Write(0x00);
}
void draw_horiz_fine(void)
{
    int i;

    POINT_COLOR = 0x0500;
    for (i = 64; i < 256; i += 24) { 
        LCD_DrawLine(0, i + 5, 239, i + 5);
        LCD_DrawLine(0, i + 10, 239, i + 10);
        LCD_DrawLine(0, i + 14, 239, i + 14);
        LCD_DrawLine(0, i + 19, 239, i + 19);
    }
}

void draw_vert_fine(void)
{
    int i;
    
    POINT_COLOR = 0x0500;
    for (i = 0; i < 240; i += 24) {     
        LCD_DrawLine(i + 5, 64, i + 5, 255);
        LCD_DrawLine(i + 10, 64, i + 10, 255);
        LCD_DrawLine(i + 14, 64, i + 14, 255);
        LCD_DrawLine(i + 19, 64, i + 19, 255);
    }
}

void draw_vert(void)
{
    int i;
    
    POINT_COLOR = GREEN;
    for (i = 0; i <= 240; i += 24) {
        if (i == 240) {
            i = 239;
        }
        LCD_DrawLine(i, 64, i, 255);
    }  
    
    LCD_DrawLine(119, 64, 119, 255);
}

void draw_horiz(void)
{
    int i;
    
    POINT_COLOR = GREEN;
    for (i = 64; i <= 256; i += 24) {
        if (i == 256) {
            i = 255;
        }
        LCD_DrawLine(0, i, 239, i);
    }
    LCD_DrawLine(0, 159, 239, 159);
}

void draw_dots(void)
{
    int x, y;

    POINT_COLOR = GREEN;
    for (x = 0; x <= 240; x += 24) {
        if (x == 240) {
            x = 239;
        }
        for (y = 64; y <= 256; y += 24) {
            if (y == 256) {
                y = 255;
            }
            LCD_DrawPoint(x, y);
            if (x == 120) {
                LCD_DrawPoint(x - 1, y);
                LCD_DrawPoint(x + 1, y);
            }
            
            if (y == 160) {
                LCD_DrawPoint(x, y - 1);
                LCD_DrawPoint(x, y + 1);
            }                
        }
    }
}
    
void foo_test(int lala)
{
    int i;
    
    LCD_Fill(0,0,239,47,WHITE);
    POINT_COLOR = BLACK;
    LCD_DrawLine(0, 47, 239, 47);
    LCD_DrawLine(60, 0, 60, 47);
    LCD_DrawLine(120, 0, 120, 47);
    LCD_DrawLine(180, 0, 180, 47);
    
    Gui_StrCenter(30, 8, BLACK, WHITE, "Button", 16, 0);
    Gui_StrCenter(30, 24, BLACK, WHITE, "4", 16, 0);
    Gui_StrCenter(90, 8, BLACK, WHITE, "Button", 16, 0);
    Gui_StrCenter(90, 24, BLACK, WHITE, "5", 16, 0);
    Gui_StrCenter(150, 8, BLACK, WHITE, "Button", 16, 0);
    Gui_StrCenter(150, 24, BLACK, WHITE, "6", 16, 0);
    Gui_StrCenter(210, 8, BLACK, WHITE, "Button", 16, 0);
    Gui_StrCenter(210, 24, BLACK, WHITE, "7", 16, 0);
    
    LCD_Fill(0,48,239,63,0x39e7);
    Gui_StrCenter(120, 48, GREEN, 0x39e7, "0123456789", 16, 0);
    
    LCD_Fill(0, 64, 239, 255, 0x4208);
    
    switch (lala) {
        case 0:
            draw_horiz();
            break;
        case 1:
            draw_vert();
            break;
        case 2:
            draw_horiz();
            draw_vert();
            break;
        case 3:
            draw_dots();
            break;
        case 4:
            draw_horiz_fine();
            draw_horiz();
            break;
        case 5:
            draw_vert_fine();
            draw_vert();
            break;
        case 6:
            draw_horiz_fine();
            draw_vert_fine();
            draw_horiz();
            draw_vert();
            break;
        case 7:
            LCD_Fill(0,64,239, 255, /*0x6e1a*/0x001f);
            break;
    }
    
    LCD_Fill(0,256,239,271,0x39e7);
    Gui_StrCenter(120, 256, GREEN, 0x39e7, "ABCDEFGHIJ", 16, 0);
    LCD_Fill(0,272,239,319,WHITE);
    POINT_COLOR = BLACK;
    LCD_DrawLine(0, 272, 239, 272);
    LCD_DrawLine(60, 272, 60, 319);
    LCD_DrawLine(120, 272, 120, 319);
    LCD_DrawLine(180, 272, 180, 319);
    
    Gui_StrCenter(30, 280, BLACK, WHITE, "Button", 16, 0);
    Gui_StrCenter(30, 296, BLACK, WHITE, "0", 16, 0);
    Gui_StrCenter(90, 280, BLACK, WHITE, "Button", 16, 0);
    Gui_StrCenter(90, 296, BLACK, WHITE, "1", 16, 0);
    Gui_StrCenter(150, 280, BLACK, WHITE, "Button", 16, 0);
    Gui_StrCenter(150, 296, BLACK, WHITE, "2", 16, 0);
    Gui_StrCenter(210, 280, BLACK, WHITE, "Button", 16, 0);
    Gui_StrCenter(210, 296, BLACK, WHITE, "3", 16, 0);
    
    
    CyDelay(1000u);
}
/*******************************************************************************
* Function Name: main
********************************************************************************
*
* Summary:
*  Main function performs following functions:
*   1: Initializes the LCD and clears the display
*   2: Start the IDAC
*   3: IDAC range is set to 255uA and value to 100
*   4: Prints test name on LCD
*
* Parameters:
*  None.
*
* Return:
*  None.
*
*******************************************************************************/
int main()
{
    uint8_t foo = 10u;
    
    /* Start the LCD component */
    //LCD_Char_1_Start();           

    /* Clear LCD Display */
    //LCD_Char_1_ClearDisplay();    
    
    switch (display_mode) {
        case HORIZ:
        case XHATCH_HORIZ:
        case HORIZ_FINE:
        case XHATCH_HORIZ_FINE:
            ModeReg_Write(0);
            break;
            
        case VERT:
        case XHATCH_VERT:
        case VERT_FINE:
        case XHATCH_VERT_FINE:
            ModeReg_Write(1);
            break;
            
        case DOTS:
            ModeReg_Write(2);
            break;
    }

    Sweep_Comp_Start();
    //StepX_Buffer_Start();
    //StepY_Buffer_Start();
    
    TS1_Comp_Start();
    TSn_Comp_Start();
       
    /* Start the IDAC component */
    Sweep_IDAC_Start();
    StepX_IDAC_Start();
    StepY_IDAC_Start();
    
    Sweep_Tick_Start();
    
    Readout_Init();
    
    CyGlobalIntEnable;
    
    Sweep_Tick_WritePeriod(100);
    
    Sweep_End_StartEx(Sweep_End_ISR);
    
    Readout_Write(0, 0);
    
    TS_Int_StartEx(TS_ISR);
  
    /* Sets the IDAC full scale range to 255uA */
    Sweep_IDAC_SetRange(Sweep_IDAC_RANGE_255uA);    
    /* Init the sweep IDAC value */
    Sweep_IDAC_SetValue(132); 
    
    LCD_Init();
    
    while(1) {
        int i;
                
        for (i = 0; i <= 7; i++) {
            //main_test();
            //Test_Color();
            //Test_FillRec();
            //Test_Circle();
            //Test_Triangle();
            //English_Font_test();
            foo_test(i);
            //Rotate_Test();
            //CyDelay(10000u);
        }
    }
    
}


/* [] END OF FILE */

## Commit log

2021-07-28 Add eagle files and board outline.
    [V1.brd, V1.sch]
2021-07-29 Clarify language around board width.
2021-08-02 Add schematic snippets for timeslot interface
2021-08-03 Update text, add breakout board photo.
2021-08-05 Add discrete current sink design concept
2021-08-05 Repeat resistor values vs supply voltage warning.
2022-01-09 Minor edits for clarity & flow.
2022-01-09 Be specific about the current sourced by T2.
2022-01-22 Update current sink schematic and description to include THAT 300 enhanced Wilson current mirror that was deemed necessary in testing.
2022-05-19 Add TODO list, including details of driver chip used in Bodnar pulser.
2022-05-20 Add photo of readout/pattern prototype board.
2022-12-27 Update readout circuit.
2022-12-27 Actually add the PSOC circuitry.
2022-12-27 Add complete schematic for readout current outputs.
2022-12-29 Fix incorrect current for 5K36 resistor
2023-07-04 Update to reflect updated TS input circuitry, based on 7D15. TODO: update schematic & add screenshots
2023-07-04 Add scope plots of new input conditioning circuitry.
2023-07-04 Add reminder to add schematic detail.
2023-07-04 Update TS pulse conditioning schematic.
2023-07-04 Airbrush bogus pin numbers out of image.
2023-07-04 Fix resistor values in PSOC input image.
2023-07-04 Update interrupt text in image (rising edge, not falling)
2024-12-17 Update readout current sinks to simplified V4 design.
2025-01-04 Cleanup backplane signal driver image.
2025-01-04 Further image cleanup of backplane driver circuit.
